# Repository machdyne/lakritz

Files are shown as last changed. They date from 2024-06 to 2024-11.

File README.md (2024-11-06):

# Lakritz Computer

Lakritz is an FPGA computer designed by Lone Dynamics Corporation.

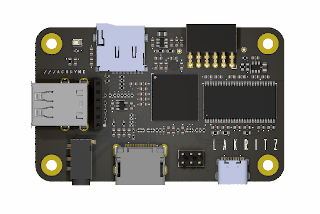
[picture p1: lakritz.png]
Lakritz Computer


This repo contains schematics, PCB layouts, pinouts, a 3D-printable case, example gateware and documentation.

Find more information on the [Lakritz product page](https://machdyne.com/product/lakritz-computer/).

## Programming Lakritz

Lakritz has a JTAG interface and ships with a [DFU bootloader](https://github.com/machdyne/tinydfu-bootloader) that allows the included flash [MMOD](https://machdyne.com/product/mmod) to be programmed over the USB-C port.

### DFU

The DFU bootloader is available for 5 seconds after power-on, issuing a DFU command during this period will stop the boot process until the DFU device is detached. If no command is received the boot process will continue and the user gateware will be loaded.

Install [dfu-util](http://dfu-util.sourceforge.net) (Debian/Ubuntu):

```
$ sudo apt install dfu-util
```

Update the user gateware on the flash MMOD:

```
$ sudo dfu-util -a 0 -D image.bit
```

Detach the DFU device and continue the boot process:

```
$ sudo dfu-util -a 0 -e
```

It is possible to update the bootloader itself using DFU but you shouldn't attempt this unless you have a JTAG programmer (or another method to program the MMOD) available, in case you need to restore the bootloader.

### JTAG

These examples assume you're using a "USB Blaster" JTAG cable, see the header pinout below. You will need to have [openFPGALoader](https://github.com/trabucayre/openFPGALoader) installed.

Program the configuration SRAM:

```
openFPGALoader -c usb-blaster image.bit
```

Program the flash MMOD:

```
openFPGALoader -f -c usb-blaster images/bootloader/tinydfu_lakritz.bit
```

## Blinky 

Building the blinky example requires [Yosys](https://github.com/YosysHQ/yosys), [nextpnr-ecp5](https://github.com/YosysHQ/nextpnr) and [Project Trellis](https://github.com/YosysHQ/prjtrellis).

Assuming they are installed, you can simply type `make` to build the gateware, which will be written to output/lakritz.bit. You can then use [openFPGALoader](https://github.com/trabucayre/openFPGALoader) or dfu-util to write the gateware to the device.

## Linux

See the [Kakao Linux](https://github.com/machdyne/kakao) repo for the latest instructions.

### Prebuilt Images

Copy the files from the `images/linux` and `images/v0/25f` directory to the root directory of a FAT-formatted MicroSD card along with the files from the `images` directory in the [Kakao Linux](https://github.com/machdyne/kakao) repo.

Lakritz ships with LiteX gateware on the user gateware section of the MMOD that is compatible with these images. After several seconds the Linux penguin should appear on the screen (HDMI) followed by a login prompt.

### Building Linux

Please follow the setup instructions in the [linux-on-litex-vexriscv](https://github.com/litex-hub/linux-on-litex-vexriscv) repo and then:

1. Build the Linux-capable gateware:

```
$ cd linux-on-litex-vexriscv
$ ./make.py --board lakritz --uart-baudrate 115200 --dcache-size 64 --icache-size 64 --dcache-ways=1 --icache-ways=1 --dtlb-size 2 --itlb-size 2 --build
```

NOTE: This may fail, if so:

```
$ cd build/lakritz/gateware
```

Edit `lakritz.ys` and add the `-abc2` option as shown below:

```
synth_ecp5  -top lakritz -abc2
```

Now run:

```
$ bash build_lakritz.sh
```

2. Write the gateware to the MMOD using USB DFU:

```
$ sudo dfu-util -a 0 -D build/lakritz/gateware/lakritz.bit
```

3. Copy the device tree binary `build/lakritz/lakritz.dtb` to a FAT-formatted MicroSD card.

4. Build the Linux kernel and root filesystem:

See the [Kakao Linux](https://github.com/machdyne/kakao?tab=readme-ov-file#optional-building-kakao-linux) repo for instructions.

5. Copy the Image and rootfs.cpio files generated in the previous step to the boot partition of the MicroSD card, in addition to the following files:

6. Copy the OpenSBI binary (included in this repo as `lakritz/images/linux/opensbi.bin`) to the MicroSD card. Alternatively, you can build this binary by following [these instructions](https://github.com/litex-hub/linux-on-litex-vexriscv#-generating-the-opensbi-binary-optional).

7. Copy `lakritz/images/linux/boot.json` to the MicroSD card.

8. Power-cycle Lakritz. After Linux has finished booting you should see a login prompt on the HDMI display.

## JTAG Header

The 3.3V JTAG header can be used to program the FPGA SRAM as well as the MMOD flash memory. It can also be used to provide power (5V) to the board.

```
2 4 6
1 3 5
```

| Pin | Signal |
| --- | --- |
| 1 | TCK |
| 2 | TDI |
| 3 | TDO |
| 4 | TMS |
| 5 | 5V0 |
| 6 | GND |

## Resources

 * [fpga-dac audio player](https://github.com/machdyne/fpga-dac)

## Board Revisions

| Revision | Notes |
| --- | ----- |
| V0 | Initial version |

## License

The contents of this repo are released under the [Lone Dynamics Open License](LICENSE.md) with the following exceptions:

- The KiCad design files contain parts of the [kicad-pmod](https://github.com/mithro/kicad-pmod) library which is released under the [Apache License, Version 2.0](https://www.apache.org/licenses/LICENSE-2.0.html).

- The KiCad design files may contain symbols and footprints released under other licenses; please contact us if we've failed to give proper attribution.

Note: You can use these designs for commercial purposes but we ask that instead of producing exact clones, that you either replace our trademarks and logos with your own or add your own next to ours.

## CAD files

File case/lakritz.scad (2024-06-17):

/*
 * Lakritz Case
 * Copyright (c) 2024 Lone Dynamics Corporation. All rights reserved.
 *
 * required hardware:
 *  - 4 x M3 x 25mm countersunk bolts
 *  - 4 x M3 nuts
 *
 */

$fn = 100;

board_width = 47;
board_thickness = 1.5;
board_length = 76;
board_height = 1.6;
board_spacing = 2;

wall = 1.5;

top_height = 20;
bottom_height = 6;

translate([wall,wall,0]) mdy_board();

translate([0,0,15])
	mdy_case_top();

translate([0,0,-15])
	mdy_case_bottom();

translate([0,0,25])
	mdy_case_cap();

module mdy_board() {
	
	difference() {
		color([0,0.5,0])
			roundedcube(board_width,board_length,board_thickness,5);
		translate([5, 5, -1]) cylinder(d=3.2, h=10);
		translate([5, 76-5, -1]) cylinder(d=3.2, h=10);
		translate([47-5, 5, -1]) cylinder(d=3.2, h=10);
		translate([47-5, 76-5, -1]) cylinder(d=3.2, h=10);
	}	
	
}

module mdy_case_cap() {

	translate([wall, wall, 0]) {
				
		difference() {
			union() {
				translate([23.5-(23.5/2),13.25,19]) cube([23.5,17.5,3]);
				translate([23.5-(21.8/2),14,15]) cube([21.8,16,5]);
			}
			translate([23.5-(20/2),15,11]) cube([20,14,10]);
		}
	}
}

module mdy_case_top() {

	translate([0,25,19])
		rotate([90,0,270])
			translate([-0,-10,0])
				linear_extrude(1)
					text("L A K R I T Z", size=4, halign="center",
						font="Liberation Sans:style=Bold");
	

	// supports
	translate([wall, wall, 0]) {
		translate([44.5,17.1,0]) cube([3.5,7.15,19]);
	}
	
	difference() {
				
		color([0.5,0.5,0.5])
			roundedcube(board_width+(wall*2),board_length+(wall*2),top_height,5);

		// cutouts
			
		translate([2,9.5,-2])
			roundedcube(board_width-1.25,board_length-16,20,5);

		translate([9.5,2,-2])
			roundedcube(board_width-16,board_length,20,5);			
	
		translate([wall, wall, 0]) {

			// vents
			translate([47/2-(15/2),60,0]) rotate([0,0,-10]) cube([15,1,25]);
			translate([47/2-(15/2),55,0]) rotate([0,0,-10]) cube([15,1,25]);
			translate([47/2-(15/2),50,0]) rotate([0,0,-10]) cube([15,1,25]);
	
			// USBC
			translate([30,60.2-(9.5/2),0]) cube([30,9.5,3.5]);

			// DDMI
			translate([30,32-(15.5/2),-1]) cube([30,15.5,6+1]);

			// AUDIO
			translate([30,14-(6.2/2),-1]) cube([30,6.2,5+1]);
			
			// DUAL USBA
			translate([23.5-(15/2),-5,0]) cube([15,10,15.8+1]);
	
			// SD
			translate([-10,26-(15/2),-2]) cube([15,15,2+2]);

			// LED
			//translate([-10,12.5-(2/2),0]) cube([20,1,1]);
			
			// PMODA
			translate([-10,53.625-(16/2),0]) cube([25,16,5.1]);

			// MMOD VERTICAL
			translate([23.5-(22/2),14,15]) cube([22,16,10]);
			
			// bolt holes
			translate([5, 5, -21]) cylinder(d=3.5, h=40);
			translate([5, 76-5, -21]) cylinder(d=3.5, h=40);
			translate([47-5, 5, -20]) cylinder(d=3.5, h=40);
			translate([47-5, 76-5, -21]) cylinder(d=3.5, h=40);

			// flush mount bolt holes
			translate([5, 5, top_height-1.5]) cylinder(d=5.25, h=4);
			translate([5, 76-5, top_height-1.5]) cylinder(d=5.25, h=4);
			translate([47-5, 5, top_height-1.5]) cylinder(d=5.25, h=4);
			translate([47-5, 76-5, top_height-1.5]) cylinder(d=5.25, h=4);


		}
		
	}	
}

module mdy_case_bottom() {
	
	difference() {
		color([0.5,0.5,0.5])
			roundedcube(board_width+(wall*2),board_length+(wall*2),bottom_height,5);
		
		// cutouts
		translate([3,10,1.5])
			roundedcube(board_width-3,board_length-17,10,5);
				
		translate([10.5,2.5,1.5])
			roundedcube(board_width-17.5,board_length-2,10,5);

		translate([wall, wall, 0]) {
			
		// board cutout
		translate([0,0,bottom_height-board_height])
			roundedcube(board_width+0.2,board_length+0.2,board_height+1,2.5);

		translate([wall, wall, 0]) {

			// USBC
			translate([30.5,60.2-(12.5/2),1.5]) cube([15.2,12.5,10.5+1]);

		}

		// bolt holes
		translate([5, 5, -11]) cylinder(d=3.2, h=25);
		translate([5, 76-5, -11]) cylinder(d=3.2, h=25);
		translate([47-5, 5, -11]) cylinder(d=3.2, h=25);
		translate([47-5, 76-5, -11]) cylinder(d=3.2, h=25);

		// nut holes
		translate([5, 5, -1]) cylinder(d=7, h=4, $fn=6);
		translate([5, 76-5, -1]) cylinder(d=7, h=4, $fn=6);
		translate([47-5, 5, -1]) cylinder(d=7, h=4, $fn=6);
		translate([47-5, 76-5, -1]) cylinder(d=7, h=4, $fn=6);

		}
		
	}	
}

// https://gist.github.com/tinkerology/ae257c5340a33ee2f149ff3ae97d9826
module roundedcube(xx, yy, height, radius)
{
    translate([0,0,height/2])
    hull()
    {
        translate([radius,radius,0])
        cylinder(height,radius,radius,true);

        translate([xx-radius,radius,0])
        cylinder(height,radius,radius,true);

        translate([xx-radius,yy-radius,0])
        cylinder(height,radius,radius,true);

        translate([radius,yy-radius,0])
        cylinder(height,radius,radius,true);
    }
}

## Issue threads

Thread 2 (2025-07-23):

Possible aBGR8888 variant for framebuffer

Ruinland, 2025-07-23:
Hi,

Actually this is not an issue.
Just curious about the simple framebuffer setting.

Currently I see in litex-boards, it's configured to use 565
https://github.com/litex-hub/litex-boards/blob/2025.04/litex_boards/targets/machdyne_lakritz.py#L153-L159
and that's the DTS being used for Lakritz at the moment.

As I toyed around Nano-X,
some of the ported Apps requires ARGB8888,
for instance, the famous Doom :
https://github.com/machdyne/microwindows/blob/master/src/contrib/doom/i_video.c#L361-L375
(still needs to invert RGB to BGR, though)
(BTW, the port is so old, requires `-std=gnu89` )

I am wondering whether people tested with 888 generation,
or people refrained from doing so because of LUT consumption ?

Cordially yours,
Ruinland

machdyne, 2025-07-24:
On sdmode, I opened an issue about this a while back because it's a long-time mystery to me:

https://github.com/enjoy-digital/litex/issues/2201

I had fallen behind on updating the linux-on-litex-vexriscv fork and I think there were few boards missing, thanks for reminding me about this. I have now added Lakritz support here:

https://github.com/machdyne/linux-on-litex-vexriscv

Ruinland, 2025-07-26:
@machdyne Thanks for updating the repo 😃
Below are out of scope of the issue, so if you don't have time for it, just close this issue :-)

= = = = =

I get very close to have the UART enabled alongside with framebuffer.
I tried toggling "serial" in make.py of lakritz while leaving the `uart_name` stay `stub`.

This will fail at PNR. I then tried adding `abc` before `synth_ecp5 ......`, this will give me 99% usage of TRELLIS_COMB.
And re-run `./build_lakritz.sh` managed to run through and generate bitstream.

However, I then commented out `uart_name` in lakritz's section in make.py so as to let it use the default UART. The TRELLIS_COMB shoot up and fail without doubt.

Hence, I tried using `uart_name=jtag_uart`, it appears uses less TRELLIS_COMB.
With that, I then again tinkered around  `./build_lakritz.sh`.
More specifically, `synth_ecp5`, I added some options to it :
 `synth_ecp5 -dff -nowidelut -abc2 -top lakritz`

And now we are very, very close to the limitation, only 100 short for the TRELLIS_COMB :
```
Info: Device utilisation:
Info: 	          TRELLIS_IO:      54/    197    27%
Info: 	                DCCA:       7/     56    12%
Info: 	              DP16KD:      52/     56    92%
Info: 	          MULT18X18D:       4/     28    14%
Info: 	              ALU54B:       0/     14     0%
Info: 	             EHXPLLL:       2/      2   100%
Info: 	             EXTREFB:       0/      1     0%
Info: 	                DCUA:       0/      1     0%
Info: 	           PCSCLKDIV:       0/      2     0%
Info: 	             IOLOGIC:      45/    128    35%
Info: 	            SIOLOGIC:       2/     69     2%
Info: 	                 GSR:       0/      1     0%
Info: 	               JTAGG:       0/      1     0%
Info: 	                OSCG:       0/      1     0%
Info: 	               SEDGA:       0/      1     0%
Info: 	                 DTR:       0/      1     0%
Info: 	             USRMCLK:       0/      1     0%
Info: 	             CLKDIVF:       0/      4     0%
Info: 	           ECLKSYNCB:       0/     10     0%
Info: 	             DLLDELD:       0/      8     0%
Info: 	              DDRDLL:       0/      4     0%
Info: 	             DQSBUFM:       0/      8     0%
Info: 	     TRELLIS_ECLKBUF:       0/      8     0%
Info: 	        ECLKBRIDGECS:       0/      2     0%
Info: 	                DCSC:       0/      2     0%
Info: 	          TRELLIS_FF:    8253/  24288    33%
Info: 	        TRELLIS_COMB:   24388/  24288   100%
Info: 	        TRELLIS_RAMW:    1250/   3036    41%
```

Is there anything I can tweak with the `make.py` arguments ? I.e.
`./make.py --board lakritz --uart-baudrate 115200 --dcache-size 64 --icache-size 64 --dcache-ways=1 --icache-ways=1 --dtlb-size 2 --itlb-size 2 --build`

I tried to set  i/d cache size to be 32 and it seems LiteX cannot take it 😿

machdyne, 2025-07-26:
I don't know of any other options to reduce it further, but I believe this did fit on [Konfekt](https://github.com/machdyne/konfekt) and I think that's because it only has one USB host port, so by removing one of the USB host ports in the platform file you might get it to fit. That doesn't help if you need to use both USB host ports though. Let me know if you get it to build.

Ruinland, 2025-07-26:
@machdyne
My sincere thankfulness to the tip on removing one of the  USB port 🙏🙏🙏🙏
It now gets the UART and framebuffer working

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

Thank you for tolerating my newbiew questions 😅
It's really fun to play around this.

Closed 2025-07-26.

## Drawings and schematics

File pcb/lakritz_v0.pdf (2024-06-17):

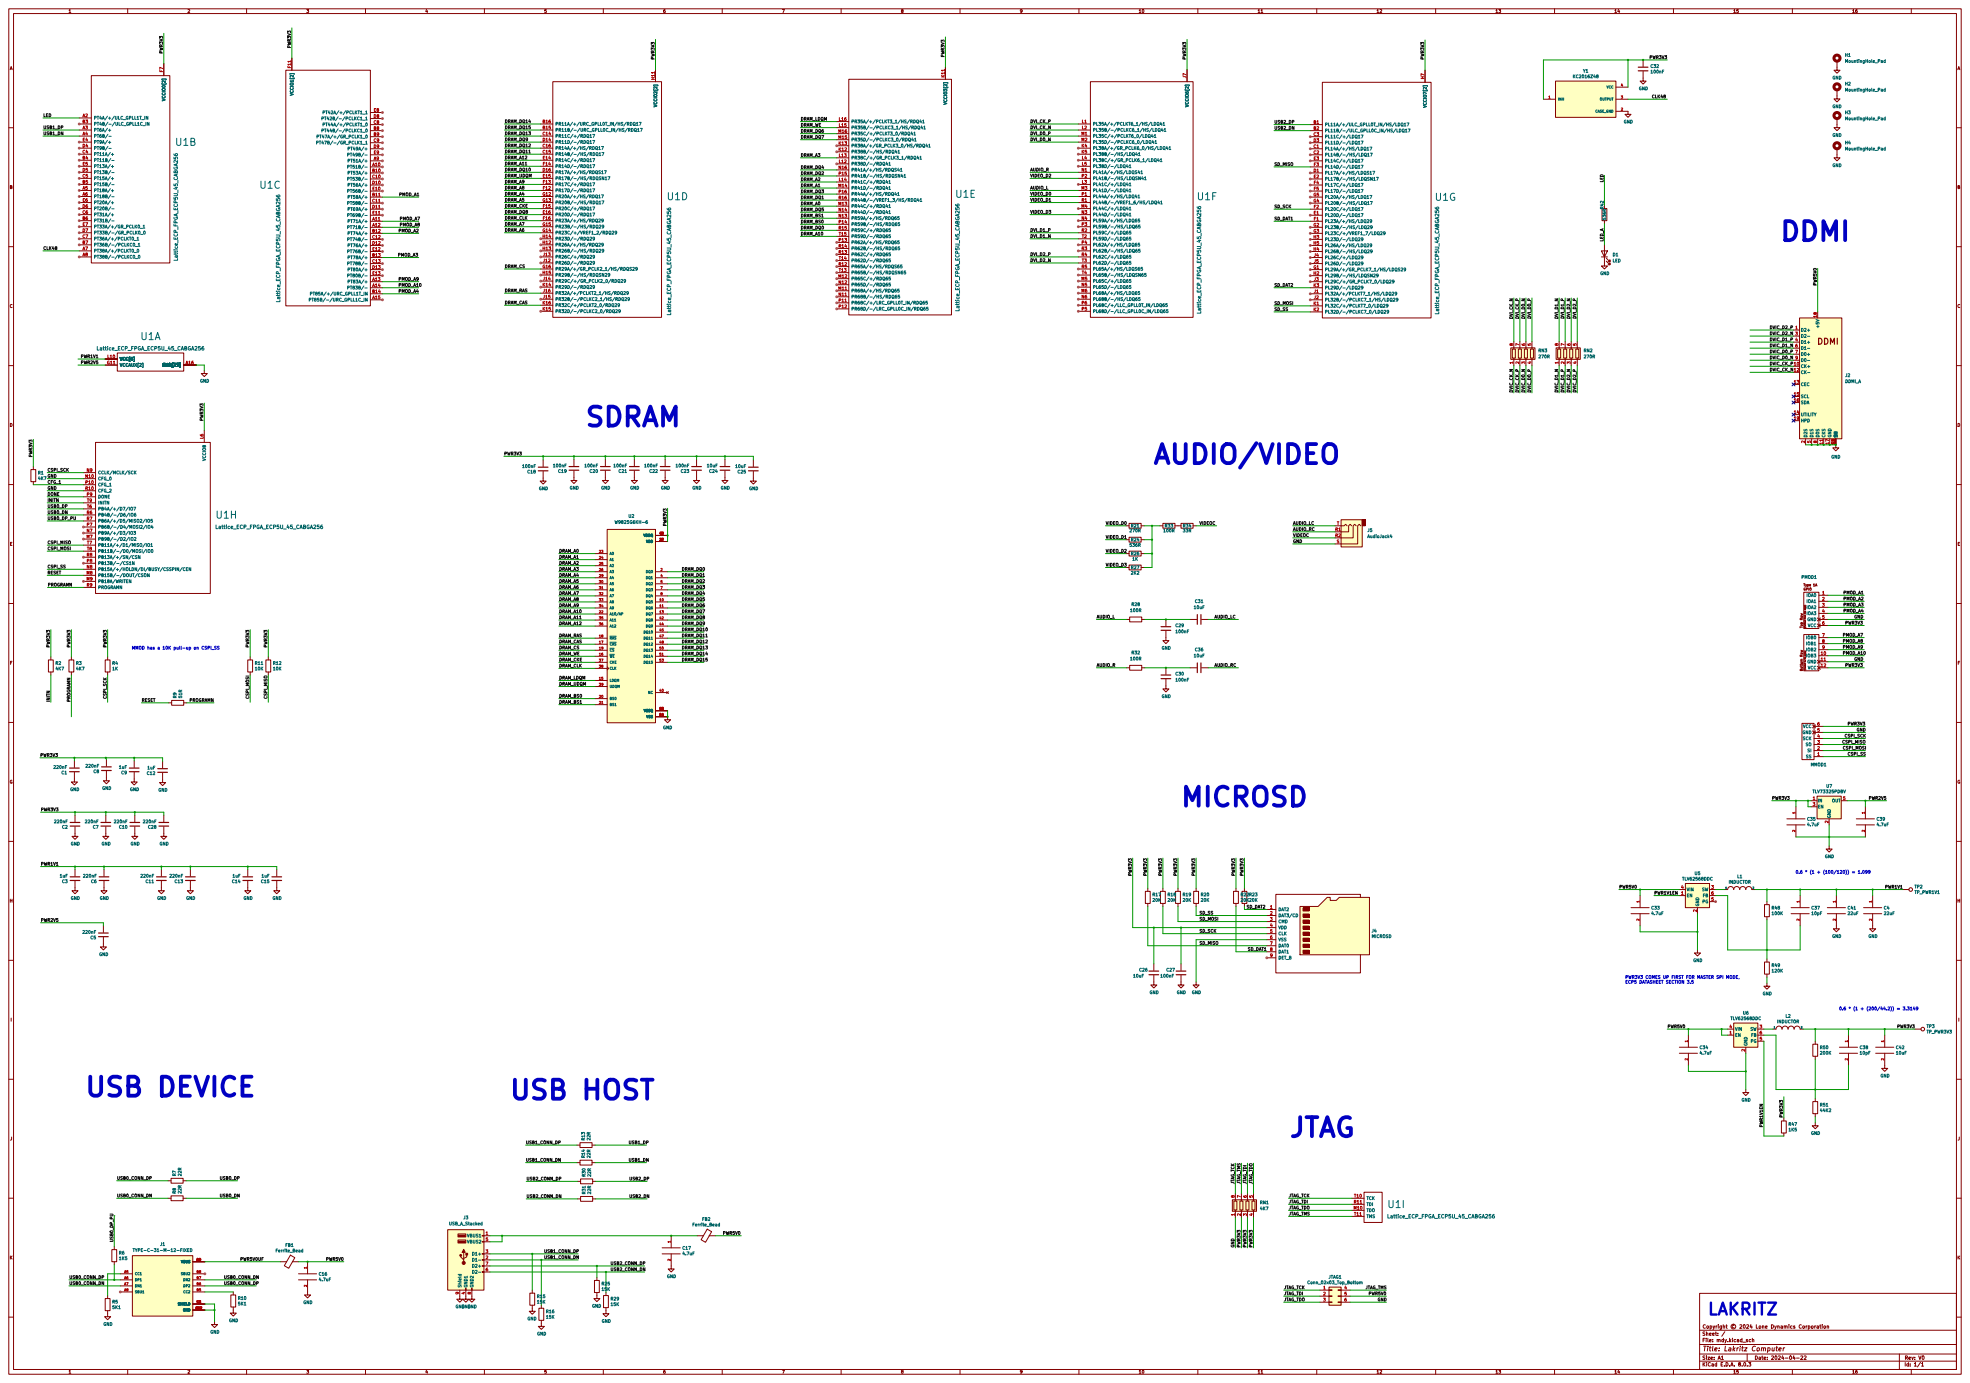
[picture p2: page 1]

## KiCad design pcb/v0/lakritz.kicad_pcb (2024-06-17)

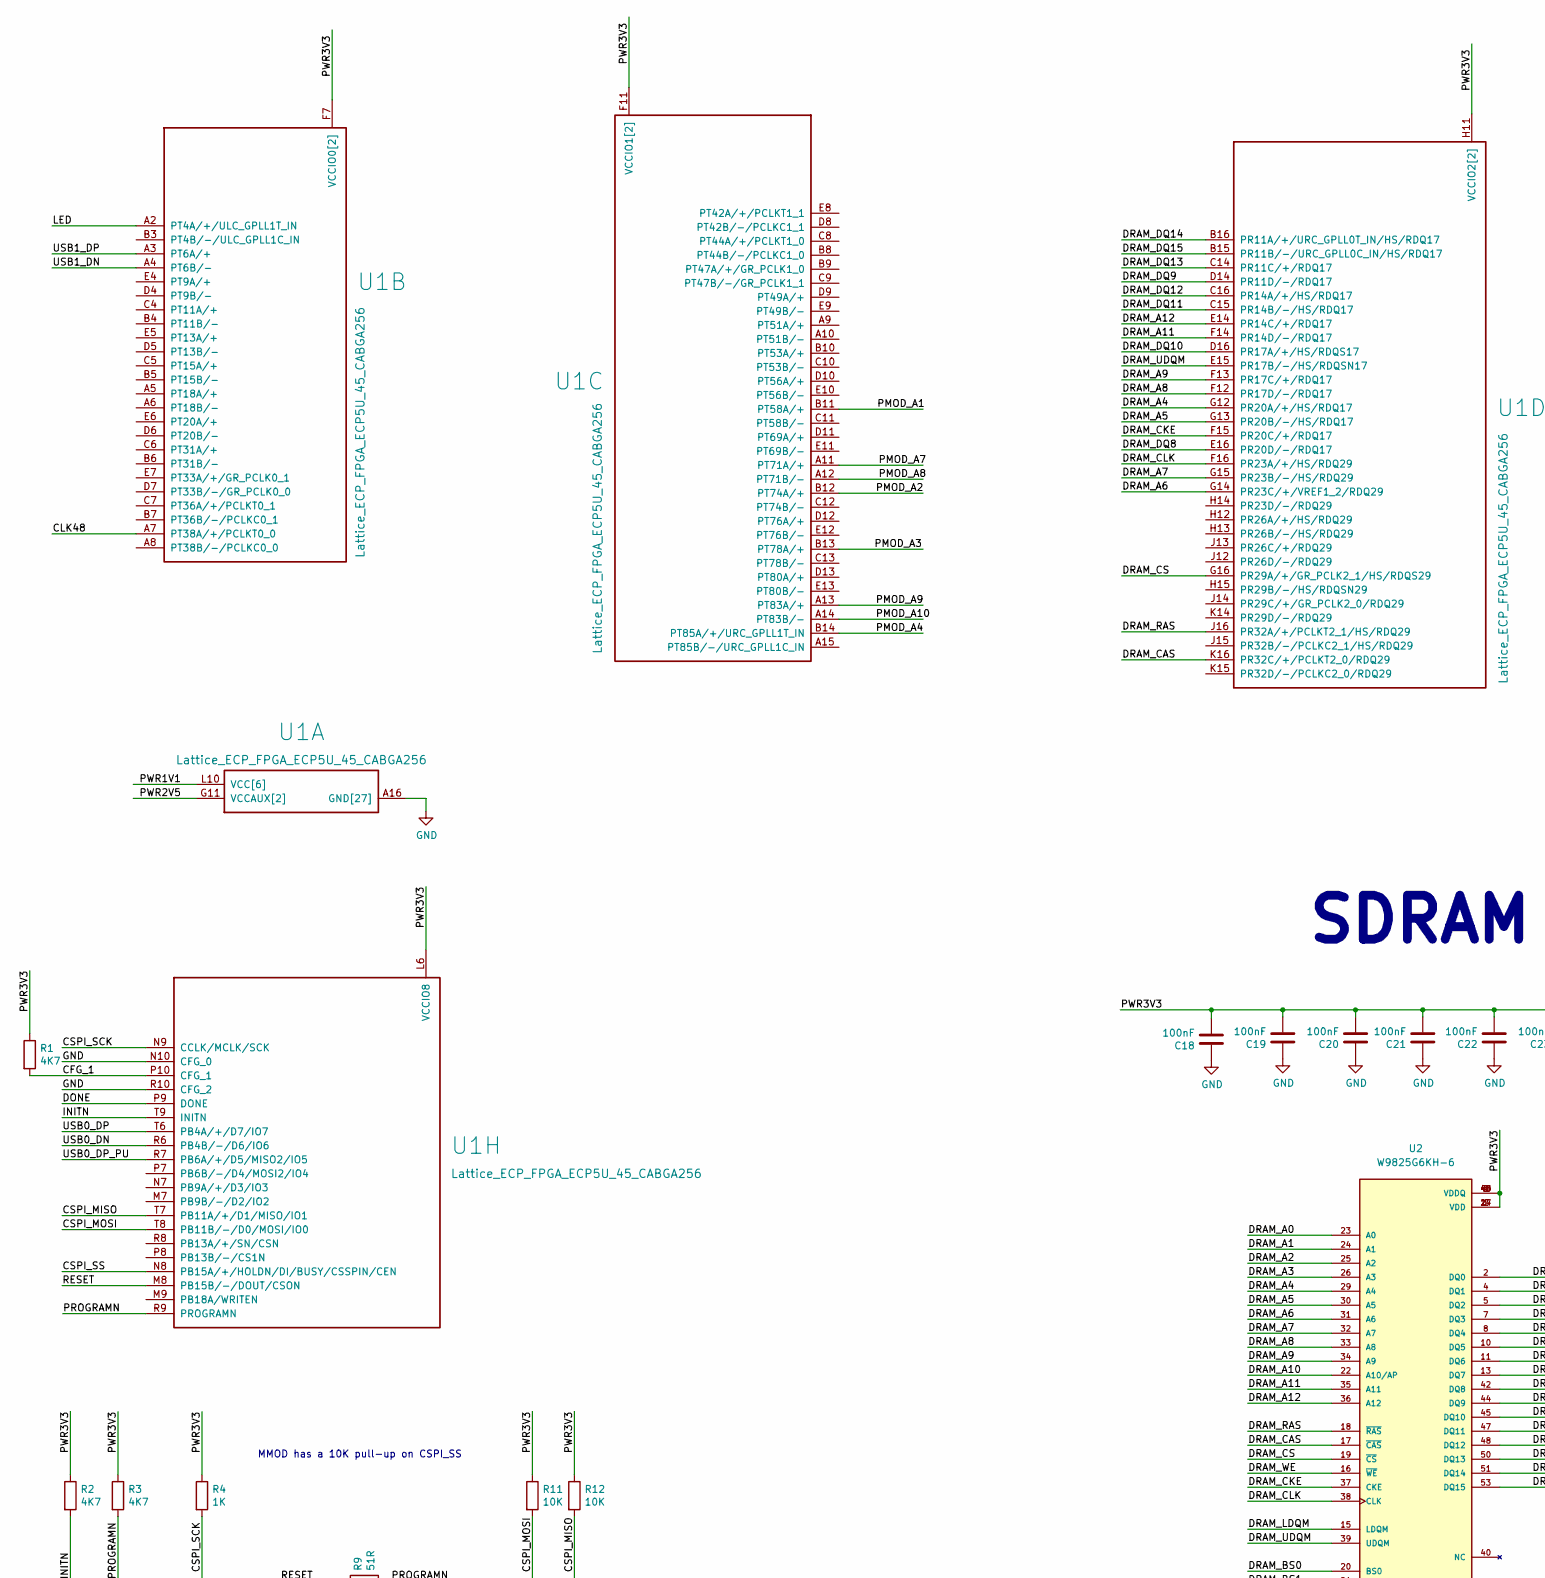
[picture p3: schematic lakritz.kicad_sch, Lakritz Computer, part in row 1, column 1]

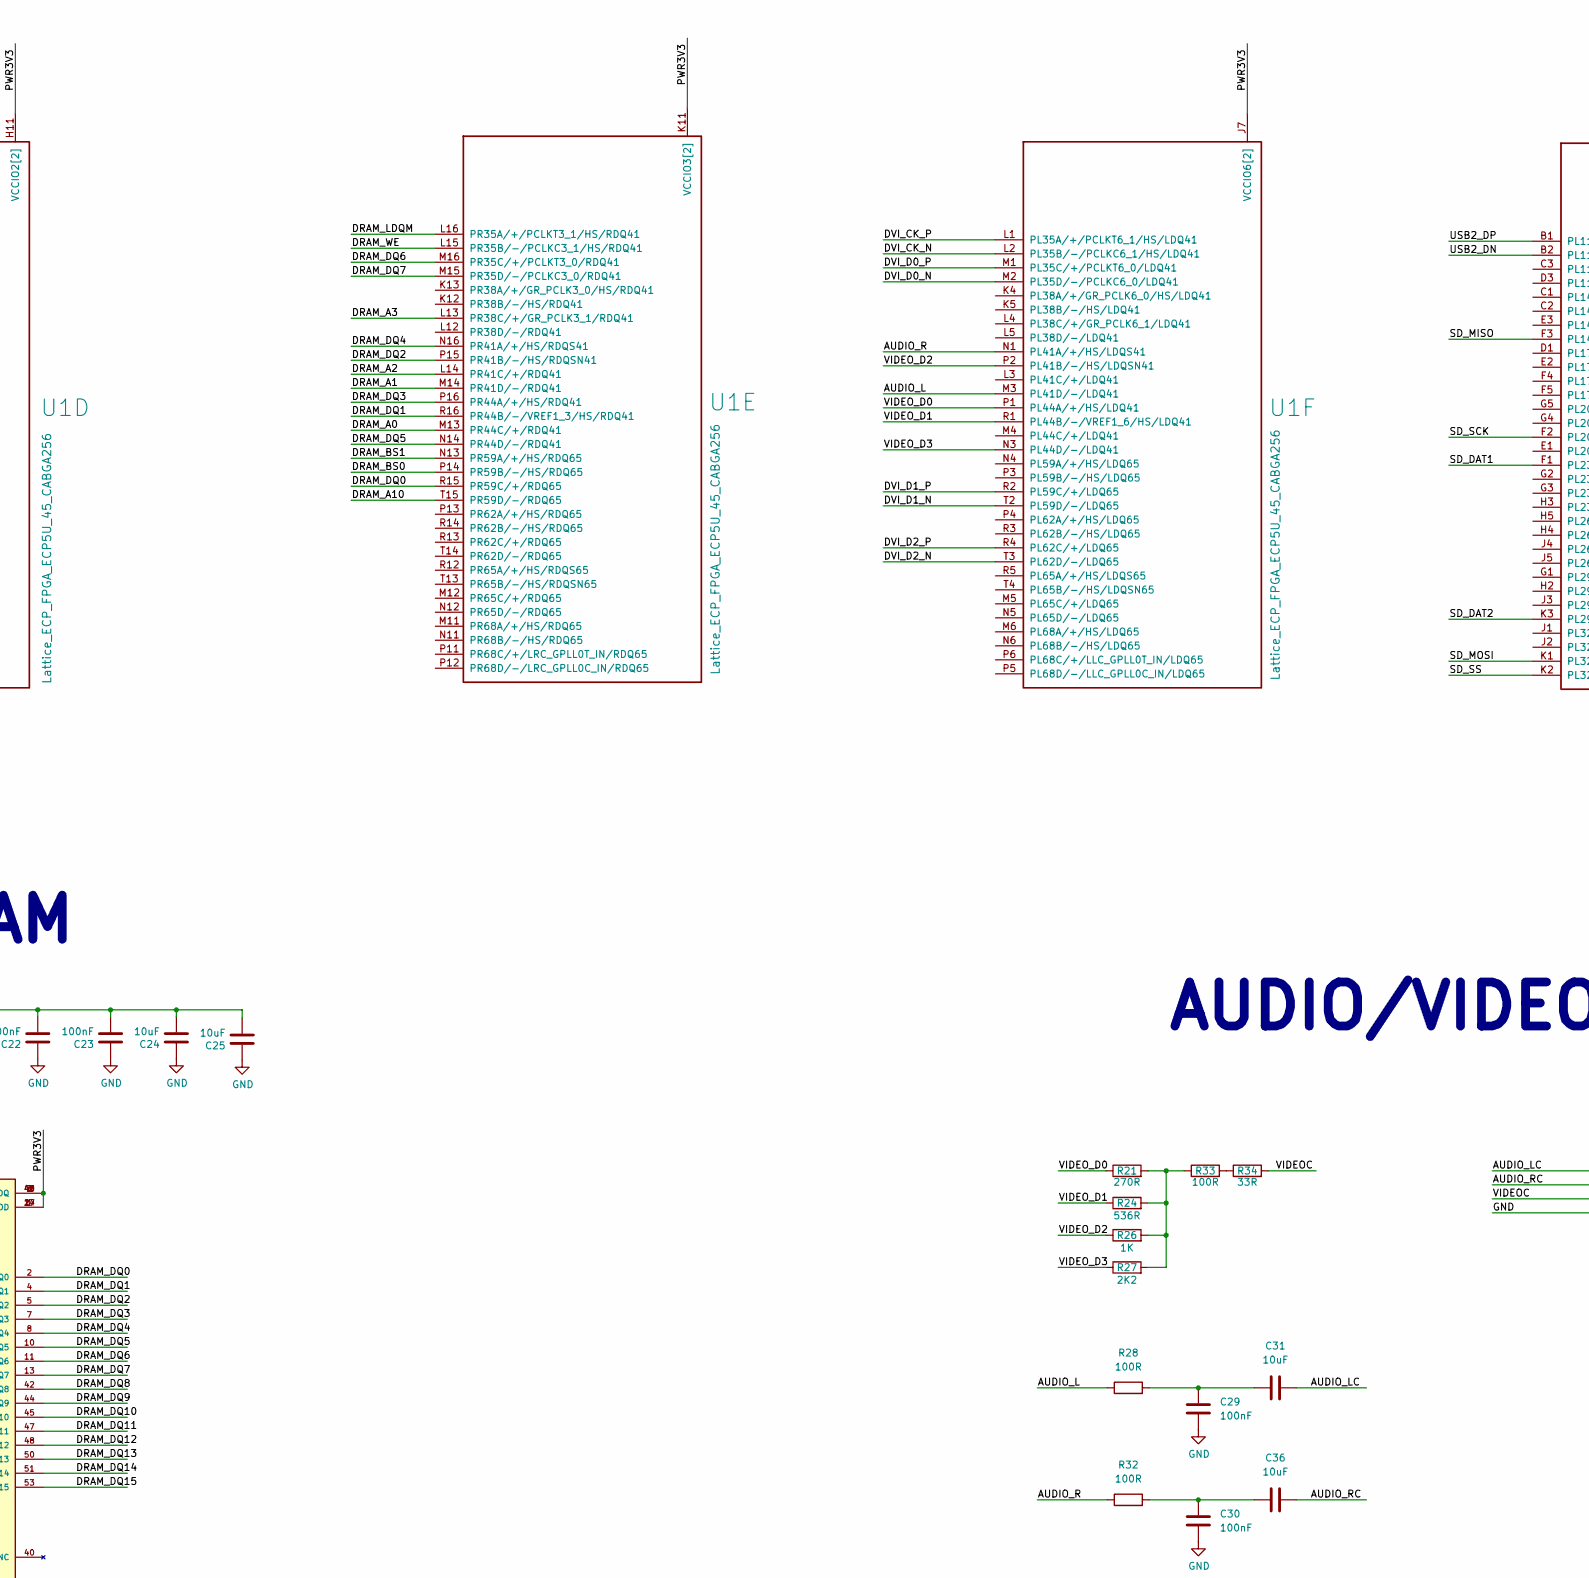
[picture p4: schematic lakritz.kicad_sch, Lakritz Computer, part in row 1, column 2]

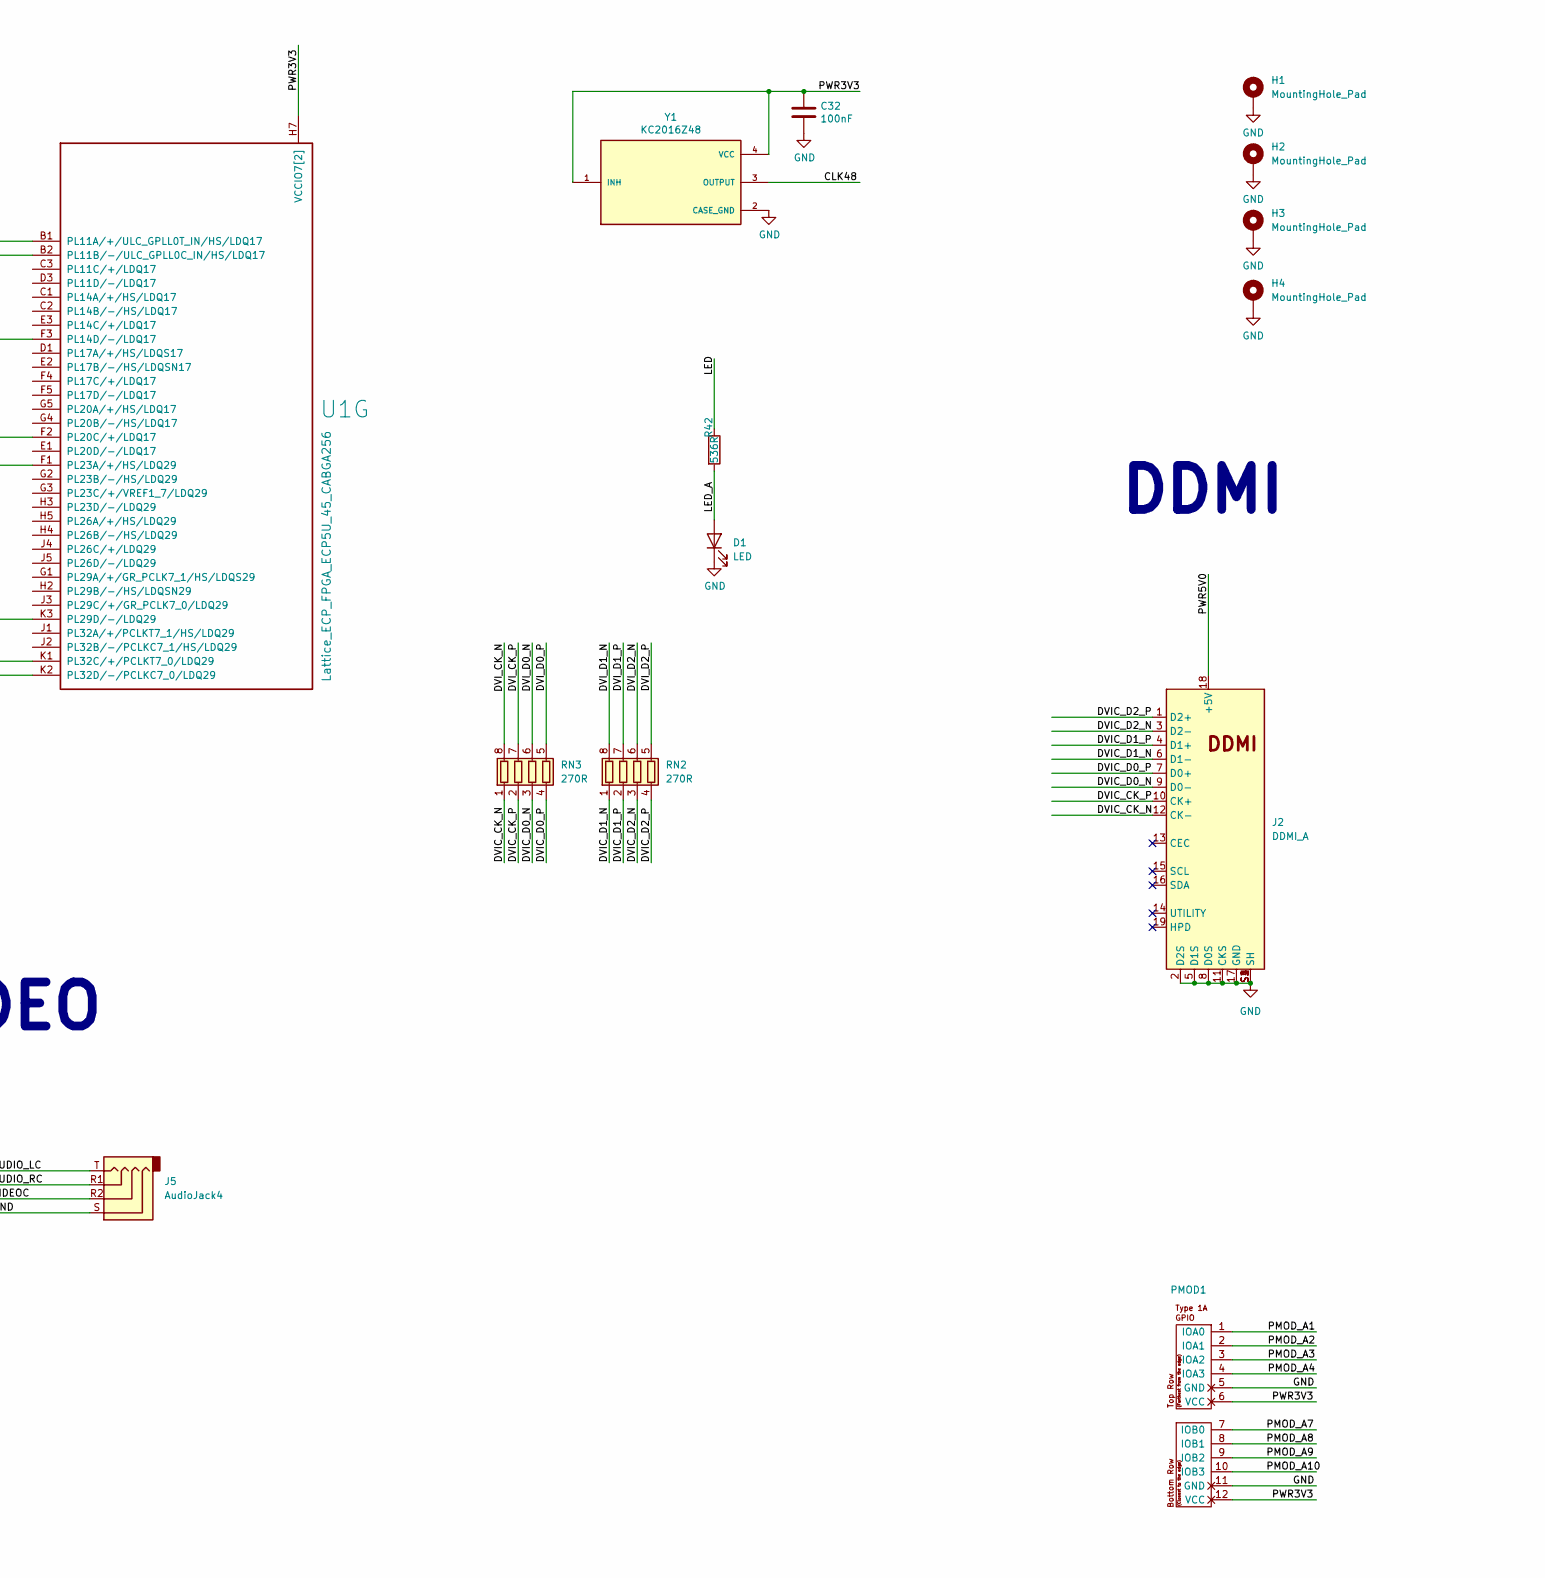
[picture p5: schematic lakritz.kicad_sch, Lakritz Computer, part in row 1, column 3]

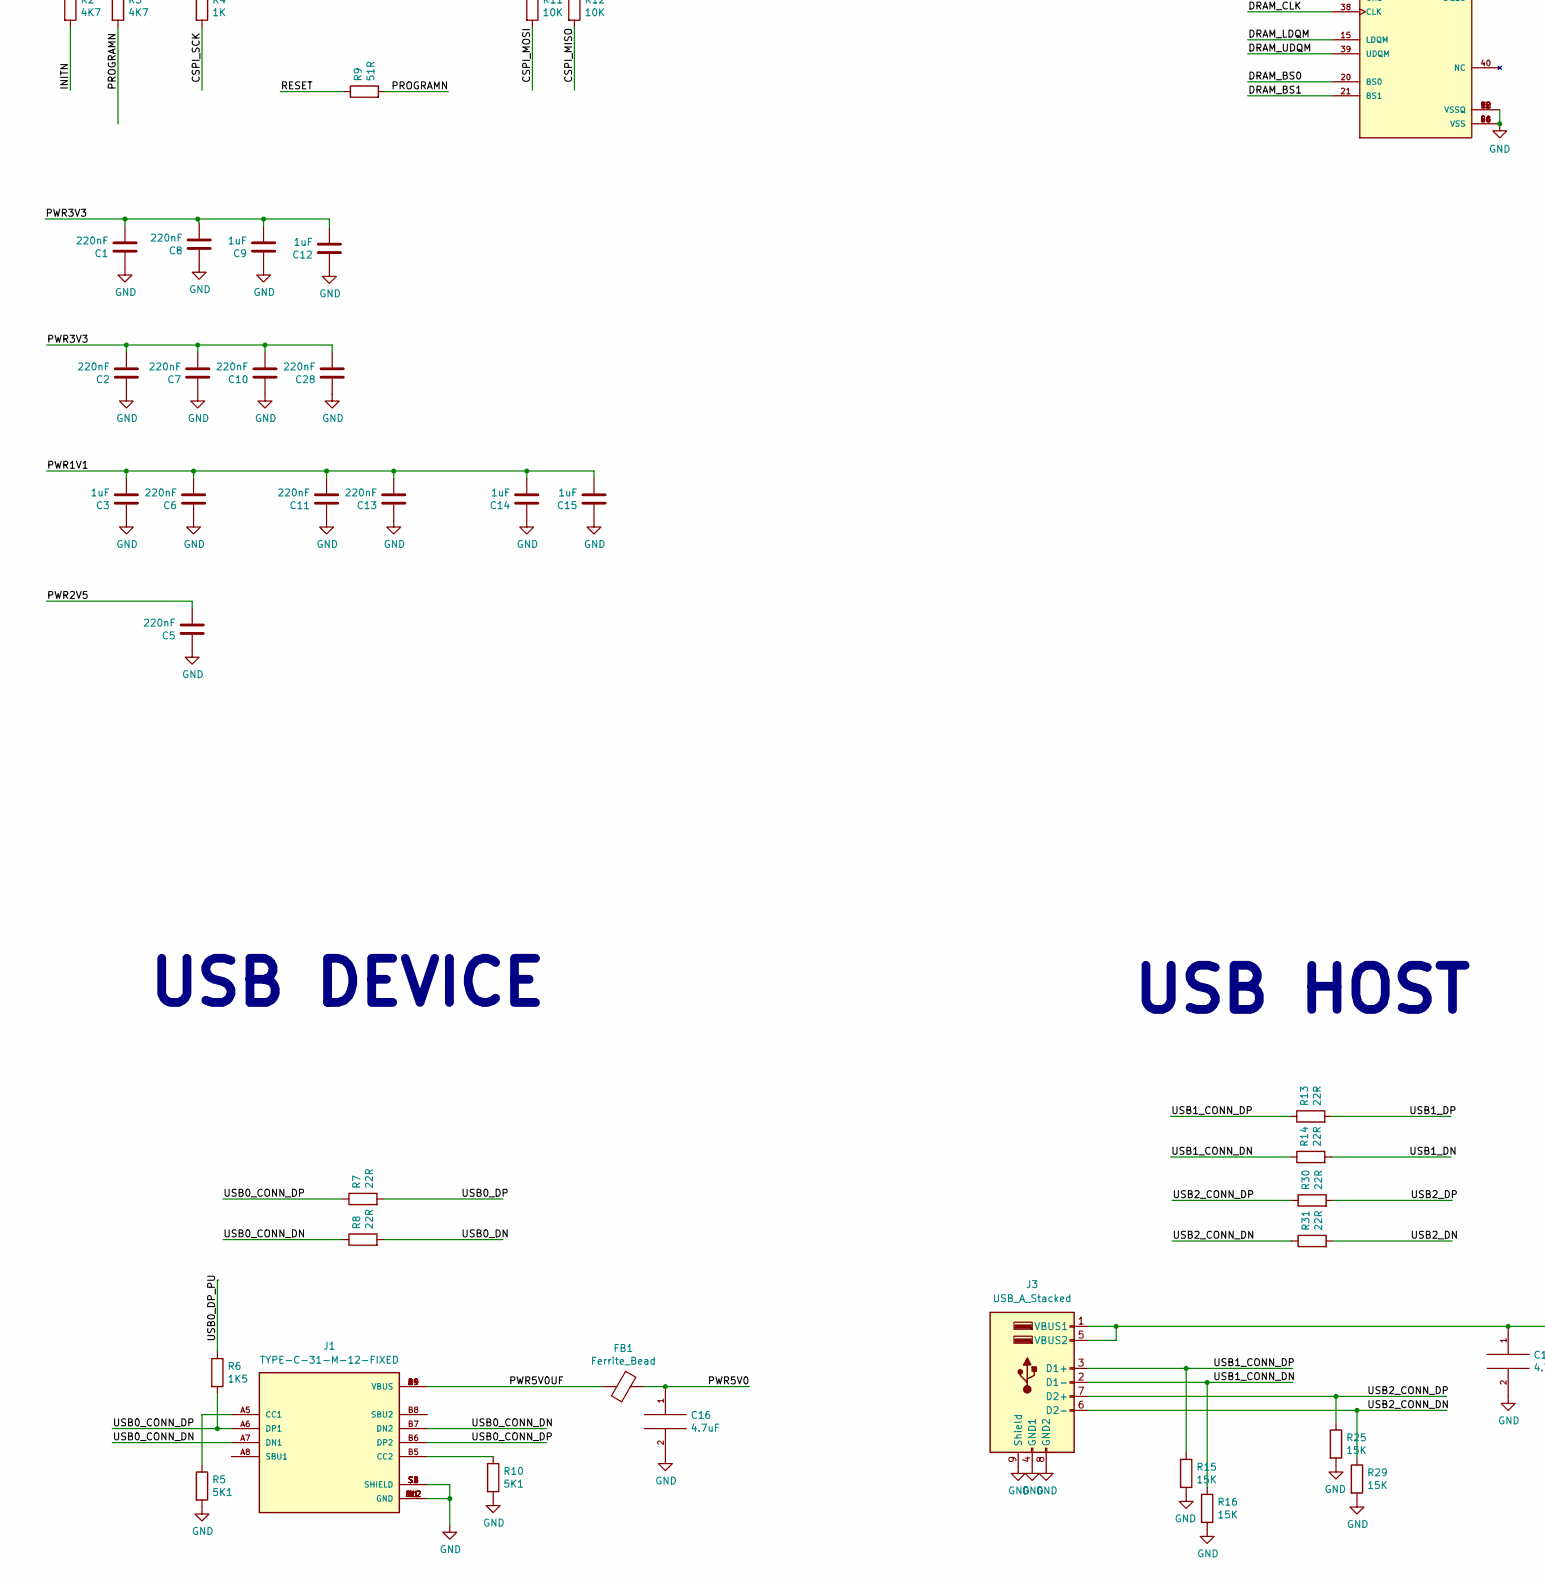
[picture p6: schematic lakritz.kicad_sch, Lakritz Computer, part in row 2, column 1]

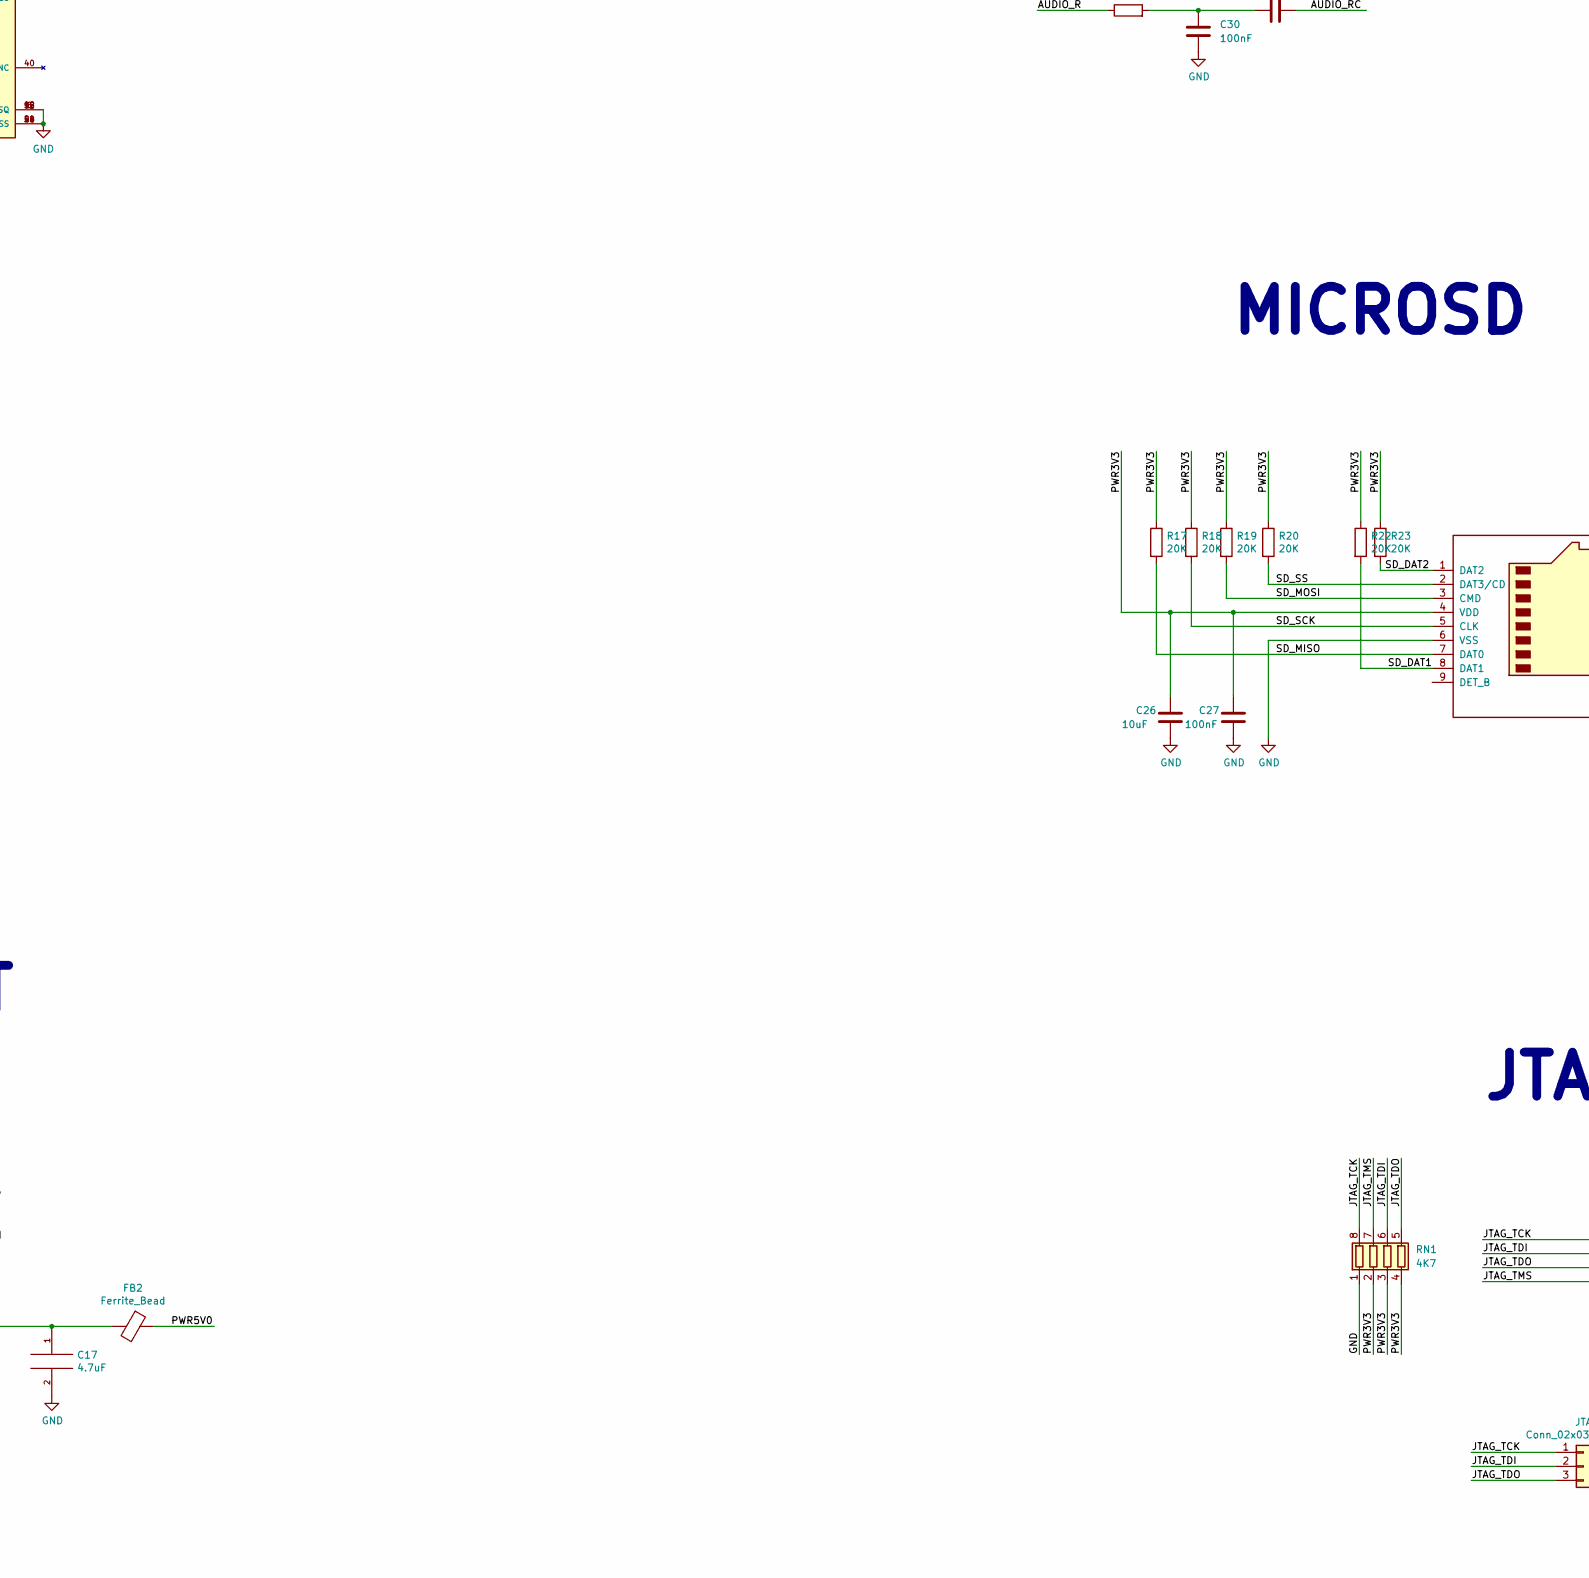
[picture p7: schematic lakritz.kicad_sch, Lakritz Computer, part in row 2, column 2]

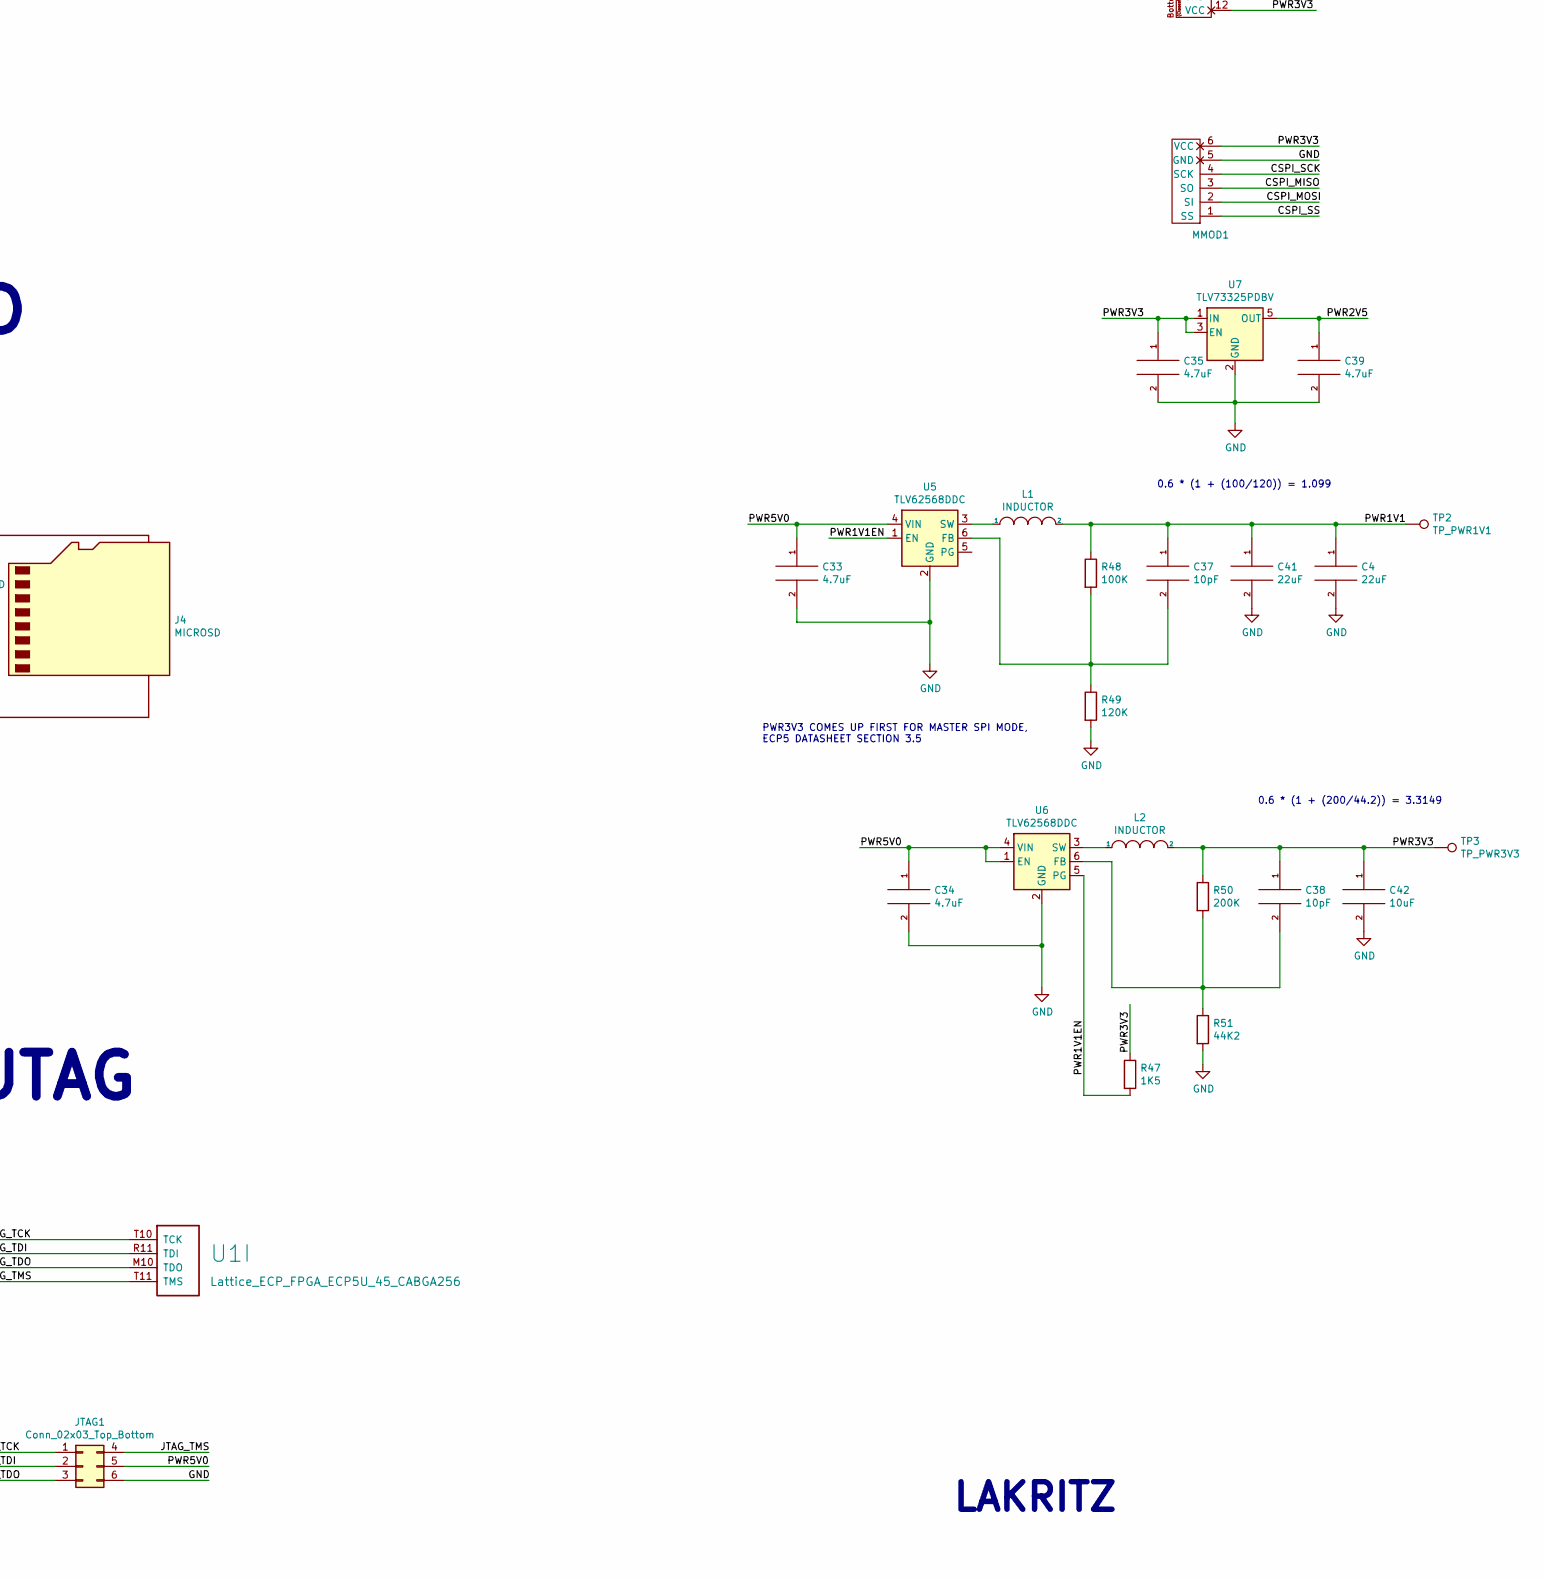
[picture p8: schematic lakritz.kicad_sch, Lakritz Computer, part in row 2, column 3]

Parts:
C1, C2, C5, C6, C7, C8, C10, C11, C13, C28: 220nF; C_0603_1608Metric
C3, C9, C12, C14, C15: 1uF; C_0603_1608Metric
C4, C41: 22uF; C_0603_1608Metric
C16, C17, C33, C34, C35, C39: 4.7uF; C_0603_1608Metric
C18, C19, C20, C21, C22, C23, C27, C29, C30, C32: 100nF; C_0603_1608Metric
C24, C25, C26, C31, C36, C42: 10uF; C_0603_1608Metric
C37, C38: 10pF; C_0603_1608Metric
D1: LED; LED_0805_2012Metric
FB1, FB2: Ferrite_Bead; R_0603_1608Metric
H1, H2, H3, H4: MountingHole_Pad; MountingHole_3.2mm_M3_Pad
J1: TYPE-C-31-M-12-FIXED; USB_C_Receptacle_HRO_TYPE-C-31-M-12-BIG-PADS; PARTREV A
J2: DDMI_A; HDMI_TE_1827059-3-FIXED
J3: USB_A_Stacked; USB_A_Wuerth_61400826021_Horizontal_Stacked
J4: MICROSD; SDCARD
J5: AudioJack4; Jack_3.5mm_PJ320D_Horizontal
JTAG1: Conn_02x03_Top_Bottom; PinHeader_2x03_P2.54mm_Vertical
L1, L2: INDUCTOR; L_0805_2012Metric
MMOD1: PMOD-Device-x1-Type-2-SPI; MMOD_Host_Socket_Vertical
PMOD1: PMOD-Device-x2-Type-1A-GPIO; PMOD_2x06_HOST
R1, R2, R3: 4K7; R_0402_1005Metric
R4, R26: 1K; R_0402_1005Metric
R5, R10: 5K1; R_0603_1608Metric
R6, R47: 1K5; R_0402_1005Metric
R7, R8, R13, R14, R30, R31: 22R; R_0402_1005Metric
R9: 51R; R_0402_1005Metric
R11, R12: 10K; R_0402_1005Metric
R15, R16, R25, R29: 15K; R_0402_1005Metric
R17, R18, R19, R20, R22, R23: 20K; R_0402_1005Metric
R21: 270R; R_0402_1005Metric
R24, R42: 536R; R_0402_1005Metric
R27: 2K2; R_0402_1005Metric
R28, R32, R33: 100R; R_0402_1005Metric
R34: 33R; R_0402_1005Metric
R48: 100K; R_0603_1608Metric
R49: 120K; R_0603_1608Metric
R50: 200K; R_0603_1608Metric
R51: 44K2; R_0603_1608Metric
RN1: 4K7; R_Array_Convex_4x0402
RN2, RN3: 270R; R_Array_Convex_4x0402
TP2: TP_PWR1V1; TestPoint_THTPad_D1.0mm_Drill0.5mm
TP3: TP_PWR3V3; TestPoint_THTPad_D1.0mm_Drill0.5mm
U1: Lattice_ECP_FPGA_ECP5U_45_CABGA256; BGA-256_14.0x14.0mm_Layout16x16_P0.8mm_Ball0.45mm_Pad0.32mm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
U2: W9825G6KH-6; SOP80P1176X120-54N; PARTREV A05
U5, U6: TLV62568DDC; SOT-23-6
U7: TLV73325PDBV; SOT-23-5
Y1: KC2016Z48; OSC_KC2016Z13.5600C1KX00; PARTREV November 2020

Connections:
/AUDIO_L: R28.1, U1.M3 (PL41D/-/LDQ41)
/AUDIO_LC: C31.2, J5.T
/AUDIO_R: R32.1, U1.N1 (PL41A/+/HS/LDQS41)
/AUDIO_RC: C36.2, J5.R1
/CFG_1: R1.2, U1.P10 (CFG_1)
/CLK48: U1.A7 (PT38A/+/PCLKT0_0), Y1.3 (OUTPUT)
/CSPI_MISO: MMOD1.3 (SO), R12.2, U1.T7 (PB11A/+/D1/MISO/IO1)
/CSPI_MOSI: MMOD1.2 (SI), R11.2, U1.T8 (PB11B/-/D0/MOSI/IO0)
/CSPI_SCK: MMOD1.4 (SCK), R4.2, U1.N9 (CCLK/MCLK/SCK)
/CSPI_SS: MMOD1.1 (SS), U1.N8 (PB15A/+/HOLDN/DI/BUSY/CSSPIN/CEN)
/DONE: U1.P9 (DONE)
/DRAM_A0: U1.M13 (PR44C/+/RDQ41), U2.23 (A0)
/DRAM_A1: U1.M14 (PR41D/-/RDQ41), U2.24 (A1)
/DRAM_A2: U1.L14 (PR41C/+/RDQ41), U2.25 (A2)
/DRAM_A3: U1.L13 (PR38C/+/GR_PCLK3_1/RDQ41), U2.26 (A3)
/DRAM_A4: U1.G12 (PR20A/+/HS/RDQ17), U2.29 (A4)
/DRAM_A5: U1.G13 (PR20B/-/HS/RDQ17), U2.30 (A5)
/DRAM_A6: U1.G14 (PR23C/+/VREF1_2/RDQ29), U2.31 (A6)
/DRAM_A7: U1.G15 (PR23B/-/HS/RDQ29), U2.32 (A7)
/DRAM_A8: U1.F12 (PR17D/-/RDQ17), U2.33 (A8)
/DRAM_A9: U1.F13 (PR17C/+/RDQ17), U2.34 (A9)
/DRAM_A10: U1.T15 (PR59D/-/RDQ65), U2.22 (A10/AP)
/DRAM_A11: U1.F14 (PR14D/-/RDQ17), U2.35 (A11)
/DRAM_A12: U1.E14 (PR14C/+/RDQ17), U2.36 (A12)
/DRAM_BS0: U1.P14 (PR59B/-/HS/RDQ65), U2.20 (BS0)
/DRAM_BS1: U1.N13 (PR59A/+/HS/RDQ65), U2.21 (BS1)
/DRAM_CAS: U1.K16 (PR32C/+/PCLKT2_0/RDQ29), U2.17 (~CAS)
/DRAM_CKE: U1.F15 (PR20C/+/RDQ17), U2.37 (CKE)
/DRAM_CLK: U1.F16 (PR23A/+/HS/RDQ29), U2.38 (CLK)
/DRAM_CS: U1.G16 (PR29A/+/GR_PCLK2_1/HS/RDQS29), U2.19 (~CS)
/DRAM_DQ0: U1.R15 (PR59C/+/RDQ65), U2.2 (DQ0)
/DRAM_DQ1: U1.R16 (PR44B/-/VREF1_3/HS/RDQ41), U2.4 (DQ1)
/DRAM_DQ2: U1.P15 (PR41B/-/HS/RDQSN41), U2.5 (DQ2)
/DRAM_DQ3: U1.P16 (PR44A/+/HS/RDQ41), U2.7 (DQ3)
/DRAM_DQ4: U1.N16 (PR41A/+/HS/RDQS41), U2.8 (DQ4)
/DRAM_DQ5: U1.N14 (PR44D/-/RDQ41), U2.10 (DQ5)
/DRAM_DQ6: U1.M16 (PR35C/+/PCLKT3_0/RDQ41), U2.11 (DQ6)
/DRAM_DQ7: U1.M15 (PR35D/-/PCLKC3_0/RDQ41), U2.13 (DQ7)
/DRAM_DQ8: U1.E16 (PR20D/-/RDQ17), U2.42 (DQ8)
/DRAM_DQ9: U1.D14 (PR11D/-/RDQ17), U2.44 (DQ9)
/DRAM_DQ10: U1.D16 (PR17A/+/HS/RDQS17), U2.45 (DQ10)
/DRAM_DQ11: U1.C15 (PR14B/-/HS/RDQ17), U2.47 (DQ11)
/DRAM_DQ12: U1.C16 (PR14A/+/HS/RDQ17), U2.48 (DQ12)
/DRAM_DQ13: U1.C14 (PR11C/+/RDQ17), U2.50 (DQ13)
/DRAM_DQ14: U1.B16 (PR11A/+/URC_GPLL0T_IN/HS/RDQ17), U2.51 (DQ14)
/DRAM_DQ15: U1.B15 (PR11B/-/URC_GPLL0C_IN/HS/RDQ17), U2.53 (DQ15)
/DRAM_LDQM: U1.L16 (PR35A/+/PCLKT3_1/HS/RDQ41), U2.15 (LDQM)
/DRAM_RAS: U1.J16 (PR32A/+/PCLKT2_1/HS/RDQ29), U2.18 (~RAS)
/DRAM_UDQM: U1.E15 (PR17B/-/HS/RDQSN17), U2.39 (UDQM)
/DRAM_WE: U1.L15 (PR35B/-/PCLKC3_1/HS/RDQ41), U2.16 (~WE)
/DVIC_CK_N: J2.12 (CK-), RN3.1 (R1.1)
/DVIC_CK_P: J2.10 (CK+), RN3.2 (R2.1)
/DVIC_D0_N: J2.9 (D0-), RN3.3 (R3.1)
/DVIC_D0_P: J2.7 (D0+), RN3.4 (R4.1)
/DVIC_D1_N: J2.6 (D1-), RN2.1 (R1.1)
/DVIC_D1_P: J2.4 (D1+), RN2.2 (R2.1)
/DVIC_D2_N: J2.3 (D2-), RN2.3 (R3.1)
/DVIC_D2_P: J2.1 (D2+), RN2.4 (R4.1)
/DVI_CK_N: RN3.8 (R1.2), U1.L2 (PL35B/-/PCLKC6_1/HS/LDQ41)
/DVI_CK_P: RN3.7 (R2.2), U1.L1 (PL35A/+/PCLKT6_1/HS/LDQ41)
/DVI_D0_N: RN3.6 (R3.2), U1.M2 (PL35D/-/PCLKC6_0/LDQ41)
/DVI_D0_P: RN3.5 (R4.2), U1.M1 (PL35C/+/PCLKT6_0/LDQ41)
/DVI_D1_N: RN2.8 (R1.2), U1.T2 (PL59D/-/LDQ65)
/DVI_D1_P: RN2.7 (R2.2), U1.R2 (PL59C/+/LDQ65)
/DVI_D2_N: RN2.6 (R3.2), U1.T3 (PL62D/-/LDQ65)
/DVI_D2_P: RN2.5 (R4.2), U1.R4 (PL62C/+/LDQ65)
/INITN: R2.2, U1.T9 (INITN)
/JTAG_TCK: JTAG1.1, RN1.8 (R1.2), U1.T10 (TCK)
/JTAG_TDI: JTAG1.2, RN1.6 (R3.2), U1.R11 (TDI)
/JTAG_TDO: JTAG1.3, RN1.5 (R4.2), U1.M10 (TDO)
/JTAG_TMS: JTAG1.4, RN1.7 (R2.2), U1.T11 (TMS)
/LED: R42.1, U1.A2 (PT4A/+/ULC_GPLL1T_IN)
/LED_A: D1.2 (A), R42.2
/PMOD_A1: PMOD1.1 (IOA0), U1.B11 (PT58A/+)
/PMOD_A2: PMOD1.2 (IOA1), U1.B12 (PT74A/+)
/PMOD_A3: PMOD1.3 (IOA2), U1.B13 (PT78A/+)
/PMOD_A4: PMOD1.4 (IOA3), U1.B14 (PT85A/+/URC_GPLL1T_IN)
/PMOD_A7: PMOD1.7 (IOB0), U1.A11 (PT71A/+)
/PMOD_A8: PMOD1.8 (IOB1), U1.A12 (PT71B/-)
/PMOD_A9: PMOD1.9 (IOB2), U1.A13 (PT83A/+)
/PMOD_A10: PMOD1.10 (IOB3), U1.A14 (PT83B/-)
/PROGRAMN: R3.2, R9.2, U1.R9 (PROGRAMN)
/PWR1V1: C3.2, C4.1, C6.2, C11.2, C13.2, C14.2, C15.2, C37.1, C41.1, L1.2, R48.1, TP2.1, U1.G6 (VCC[6]), U1.G7 (VCC[6]), U1.G9 (VCC[6]), U1.L8 (VCC[6]), U1.L9 (VCC[6]), U1.L10 (VCC[6])
/PWR1V1EN: R47.2, U5.1 (EN), U6.5 (PG)
/PWR2V5: C5.2, C39.1, U1.G11 (VCCAUX[2]), U1.L7 (VCCAUX[2]), U7.5 (OUT)
/PWR3V3: C1.2, C2.2, C7.2, C8.2, C9.2, C10.2, C12.2, C18.2, C19.2, C20.2, C21.2, C22.2, C23.2, C24.2, C25.2, C26.1, C27.1, C28.2, C32.1, C35.1, C38.1, C42.1, J4.4 (VDD), L2.2, MMOD1.6 (VCC), PMOD1.6 (VCC), PMOD1.12 (VCC), R1.1, R2.1, R3.1, R4.1, R11.1, R12.1, R17.1, R18.1, R19.1, R20.1, R22.1, R23.1, R47.1, R50.1, RN1.2 (R2.1), RN1.3 (R3.1), RN1.4 (R4.1), TP3.1, U1.F6 (VCCIO0[2]), U1.F7 (VCCIO0[2]), U1.F10 (VCCIO1[2]), U1.F11 (VCCIO1[2]), U1.H6 (VCCIO7[2]), U1.H7 (VCCIO7[2]), U1.H11 (VCCIO2[2]), U1.J6 (VCCIO6[2]), U1.J7 (VCCIO6[2]), U1.J11 (VCCIO2[2]), U1.K11 (VCCIO3[2]), U1.L6 (VCCIO8), U1.L11 (VCCIO3[2]), U2.1 (VDD), U2.3 (VDDQ), U2.9 (VDDQ), U2.14 (VDD), U2.27 (VDD), U2.43 (VDDQ), U2.49 (VDDQ), U7.1 (IN), U7.3 (EN), Y1.1 (INH), Y1.4 (VCC)
/PWR5V0: C16.1, C33.1, C34.1, FB1.1, FB2.1, J2.18 (+5V), JTAG1.5, U5.4 (VIN), U6.1 (EN), U6.4 (VIN)
/PWR5V0UF: FB1.2, J1.A4 (VBUS), J1.A9 (VBUS), J1.B4 (VBUS), J1.B9 (VBUS)
/RESET: R9.1, U1.M8 (PB15B/-/DOUT/CSON)
/SD_DAT1: J4.8 (DAT1), R22.2, U1.F1 (PL23A/+/HS/LDQ29)
/SD_DAT2: J4.1 (DAT2), R23.2, U1.K3 (PL29D/-/LDQ29)
/SD_MISO: J4.7 (DAT0), R17.2, U1.F3 (PL14D/-/LDQ17)
/SD_MOSI: J4.3 (CMD), R19.2, U1.K1 (PL32C/+/PCLKT7_0/LDQ29)
/SD_SCK: J4.5 (CLK), R18.2, U1.F2 (PL20C/+/LDQ17)
/SD_SS: J4.2 (DAT3/CD), R20.2, U1.K2 (PL32D/-/PCLKC7_0/LDQ29)
/UART_RX: U1.J1 (PL32A/+/PCLKT7_1/HS/LDQ29)
/UART_TX: U1.J2 (PL32B/-/PCLKC7_1/HS/LDQ29)
/USB0_CONN_DN: J1.A7 (DN1), J1.B7 (DN2), R8.1
/USB0_CONN_DP: J1.A6 (DP1), J1.B6 (DP2), R6.2, R7.1
/USB0_DN: R8.2, U1.R6 (PB4B/-/D6/IO6)
/USB0_DP: R7.2, U1.T6 (PB4A/+/D7/IO7)
/USB0_DP_PU: R6.1, U1.R7 (PB6A/+/D5/MISO2/IO5)
/USB1_CONN_DN: J3.2 (D1-), R14.1, R16.1
/USB1_CONN_DP: J3.3 (D1+), R13.1, R15.1
/USB1_DN: R14.2, U1.A4 (PT6B/-)
/USB1_DP: R13.2, U1.A3 (PT6A/+)
/USB2_CONN_DN: J3.6 (D2-), R29.1, R31.1
/USB2_CONN_DP: J3.7 (D2+), R25.1, R30.1
/USB2_DN: R31.2, U1.B2 (PL11B/-/ULC_GPLL0C_IN/HS/LDQ17)
/USB2_DP: R30.2, U1.B1 (PL11A/+/ULC_GPLL0T_IN/HS/LDQ17)
/VIDEOC: J5.R2, R34.2
/VIDEO_D0: R21.1, U1.P1 (PL44A/+/HS/LDQ41)
/VIDEO_D1: R24.1, U1.R1 (PL44B/-/VREF1_6/HS/LDQ41)
/VIDEO_D2: R26.1, U1.P2 (PL41B/-/HS/LDQSN41)
/VIDEO_D3: R27.1, U1.N3 (PL44D/-/LDQ41)
GND: C1.1, C2.1, C3.1, C4.2, C5.1, C6.1, C7.1, C8.1, C9.1, C10.1, C11.1, C12.1, C13.1, C14.1, C15.1, C16.2, C17.2, C18.1, C19.1, C20.1, C21.1, C22.1, C23.1, C24.1, C25.1, C26.2, C27.2, C28.1, C29.2, C30.2, C32.2, C33.2, C34.2, C35.2, C39.2, C41.2, C42.2, D1.1 (K), H1.1, H2.1, H3.1, H4.1, J1.A1 (GND), J1.A12 (GND), J1.B1 (GND), J1.B12 (GND), J1.S1 (SHIELD), J1.S2 (SHIELD), J1.S3 (SHIELD), J1.S4 (SHIELD), J2.2 (D2S), J2.5 (D1S), J2.8 (D0S), J2.11 (CKS), J2.17 (GND), J2.S1 (SH), J2.S2 (SH), J2.S3 (SH), J2.S4 (SH), J3.4 (GND1), J3.8 (GND2), J3.9 (Shield), J4.6 (VSS), J5.S, JTAG1.6, MMOD1.5 (GND), PMOD1.5 (GND), PMOD1.11 (GND), R5.2, R10.2, R15.2, R16.2, R25.2, R29.2, R49.2, R51.2, RN1.1 (R1.1), U1.A1 (GND[27]), U1.A16 (GND[27]), U1.D2 (GND[27]), U1.D15 (GND[27]), U1.F8 (GND[27]), U1.F9 (GND[27]), U1.G8 (GND[27]), U1.G10 (GND[27]), U1.H1 (GND[27]), U1.H8 (GND[27]), U1.H9 (GND[27]), U1.H10 (GND[27]), U1.H16 (GND[27]), U1.J8 (GND[27]), U1.J9 (GND[27]), U1.J10 (GND[27]), U1.K6 (GND[27]), U1.K7 (GND[27]), U1.K8 (GND[27]), U1.K9 (GND[27]), U1.K10 (GND[27]), U1.N2 (GND[27]), U1.N10 (CFG_0), U1.N15 (GND[27]), U1.R10 (CFG_2), U1.T1 (GND[27]), U1.T5 (GND[27]), U1.T12 (GND[27]), U1.T16 (GND[27]), U2.6 (VSSQ), U2.12 (VSSQ), U2.28 (VSS), U2.41 (VSS), U2.46 (VSSQ), U2.52 (VSSQ), U2.54 (VSS), U5.2 (GND), U6.2 (GND), U7.2 (GND), Y1.2 (CASE_GND)
unnamed: C29.1, C31.1, R28.2
unnamed: C30.1, C36.1, R32.2
unnamed: J1.A5 (CC1), R5.1
unnamed: J1.B5 (CC2), R10.1
unnamed: C17.1, FB2.2, J3.1 (VBUS1), J3.5 (VBUS2)
unnamed: R21.2, R24.2, R26.2, R27.2, R33.1
unnamed: R33.2, R34.1
unnamed: C37.2, R48.2, R49.1, U5.6 (FB)
unnamed: L1.1, U5.3 (SW)
unnamed: C38.2, R50.2, R51.1, U6.6 (FB)
unnamed: L2.1, U6.3 (SW)

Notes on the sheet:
LAKRITZ
PWR3V3 COMES UP FIRST FOR MASTER SPI MODE, ECP5 DATASHEET SECTION 3.5
SDRAM
0.6 * (1 + (200/44.2)) = 3.3149
MMOD has a 10K pull-up on CSPI_SS
0.6 * (1 + (100/120)) = 1.099
JTAG
USB DEVICE
AUDIO/VIDEO
DDMI
MICROSD
USB HOST

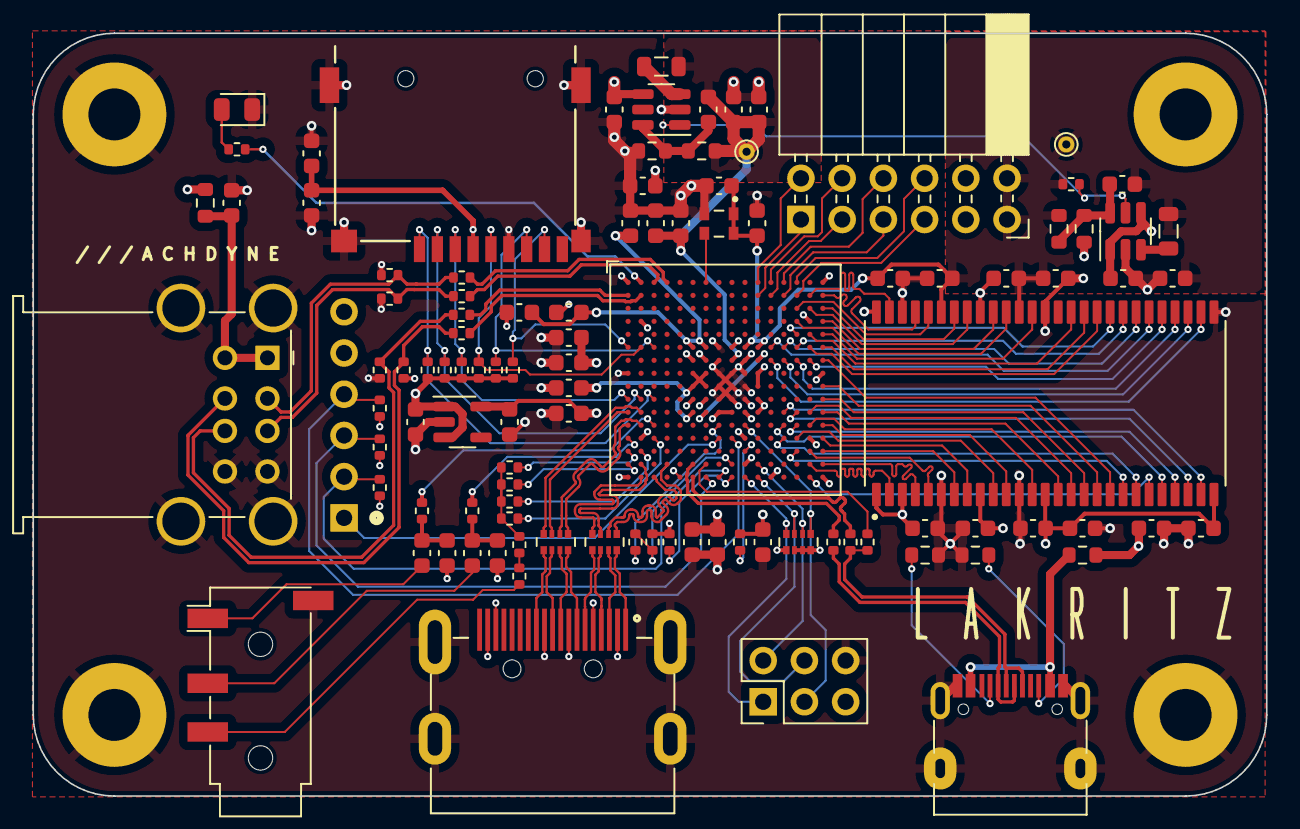
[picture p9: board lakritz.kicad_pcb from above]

Board: 4 copper layers, 76.0 x 47.0 mm, 109 parts (0 on the bottom side), 124 nets.

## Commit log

2024-06-17 add schematics/pcb layout
    [lakritz.kicad_pcb, lakritz.kicad_sch]
2024-06-17 add case
    [lakritz.scad]

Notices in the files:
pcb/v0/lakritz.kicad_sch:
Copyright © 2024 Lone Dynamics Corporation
